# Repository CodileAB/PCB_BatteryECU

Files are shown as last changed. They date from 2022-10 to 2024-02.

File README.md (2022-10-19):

Wolley Battery ECU
==================

This is the KiCad project for the Wolley Battery ECU.

Specifications
--------------

| Name | Value |
| --- | --- |
| PCB layers | 2 |
| PCB width | 103.20 mm |
| PCB height | 117.00 mm |
| Mount hole diameter | 3.20 mm |
| Bus voltage | 5 V |
| Max current | 5 A |
| Number of cells | 10 |
| Cell type | Ni-MH (AA) |
| Integrated charging | Yes |

Key Components
--------------

| Component | Part | Details |
| --- | ---- | --- |
| MCU | Infineon XMC1404_F064X200A | ARM Cortex-M0, 32-bit, 48 MHz, 200 kB flash |
| Step-down voltage regulator | TI LM22679TJ-5.0 | 42 V to 5 V switching regulator, 5 A |
| CAN transceiver | Infineon TLE7251VSJ | |
| Current sensor | MPS MCS1803GS-05P | Hall effect current sensor, 5 A |
| Temperature sensor | TI LM35DM | Precision centigrade temperature sensor |
| Battery charger | Maxim MAX1640 | Adjustable-output, switch-mode current sources with synchronous rectifier |

Licence
-------

Licenced under the CERN Open Hardware Licence v1.2.

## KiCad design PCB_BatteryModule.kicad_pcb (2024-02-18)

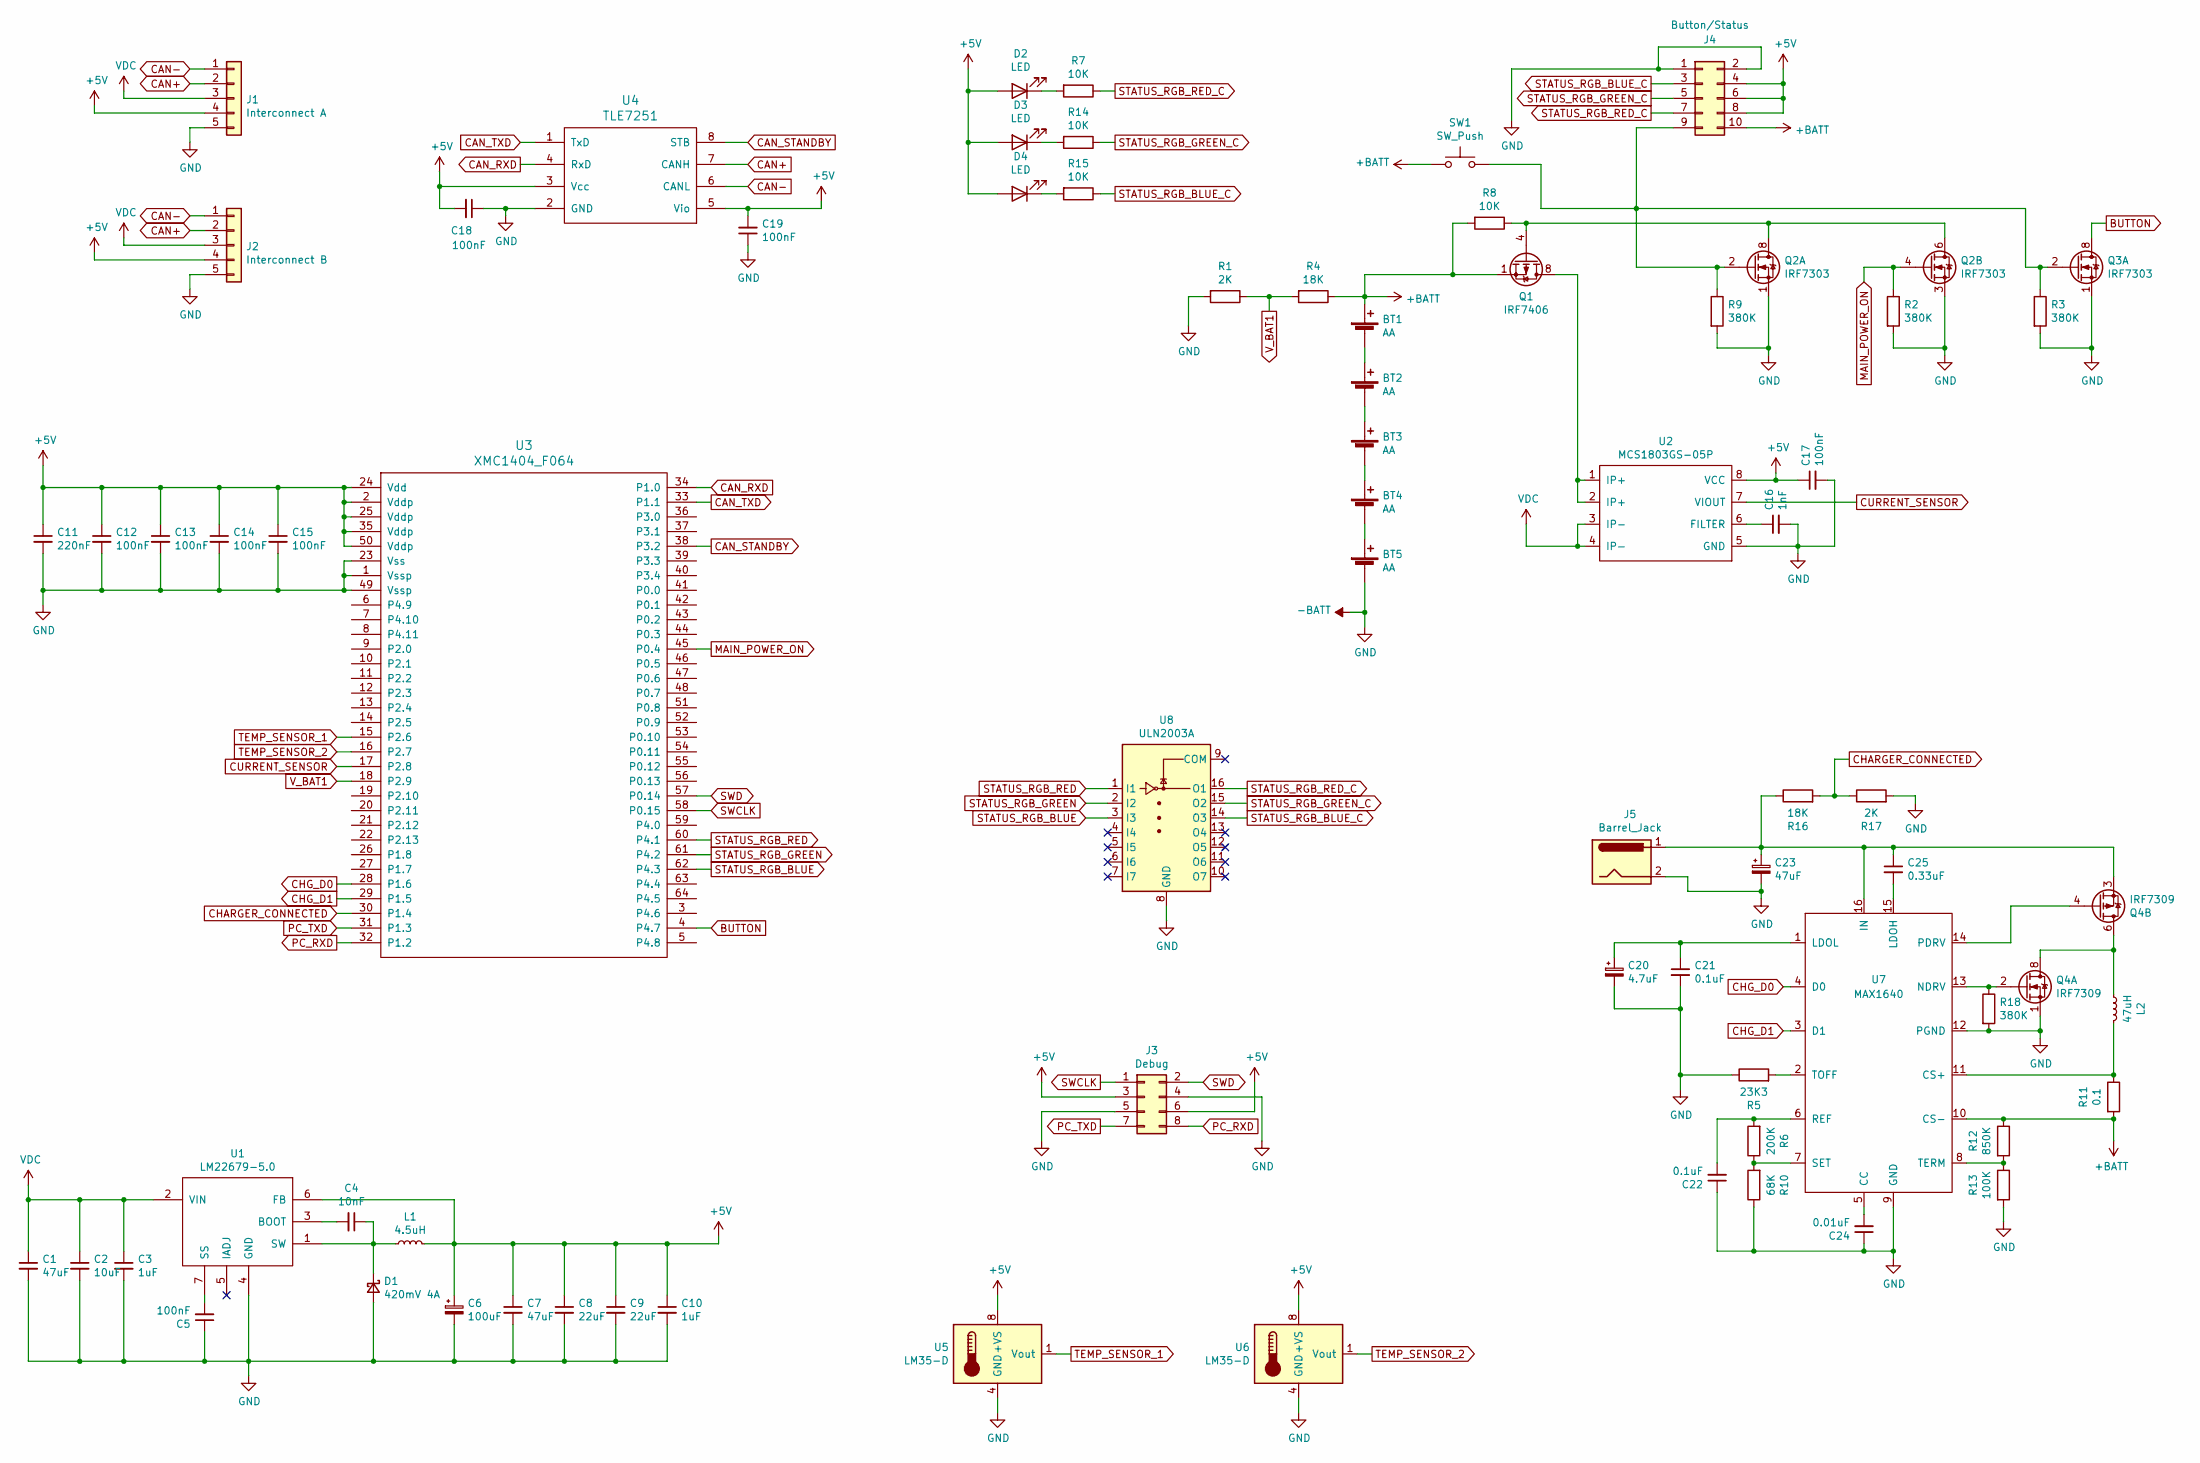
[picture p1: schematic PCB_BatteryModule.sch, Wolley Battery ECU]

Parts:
BT1, BT2, BT3, BT4, BT5: AA; Battery_AA_THT_Keystone_590
C1, C7: 47uF; C_0805_HandSoldering
C2: 10uF; C_0805_HandSoldering
C3, C10: 1uF; C_0805_HandSoldering
C4: 10nF; C_0805_HandSoldering
C5, C12, C13, C14, C15, C17, C18, C19: 100nF; C_0805_HandSoldering
C6: 100uF; CP_EIA-7343-43_Kemet-X_Pad2.25x2.55mm_HandSolder
C8, C9: 22uF; C_0805_HandSoldering
C11: 220nF; C_0805_HandSoldering
C16: 1nF; C_0805_HandSoldering
C20: 4.7uF; C_0805_HandSoldering
C21, C22: 0.1uF; C_0805_HandSoldering
C23: 47uF; CP_EIA-7343-43_Kemet-X_Pad2.25x2.55mm_HandSolder
C24: 0.01uF; C_0805_HandSoldering
C25: 0.33uF; C_0805_HandSoldering
D1: 420mV 4A; D_SMC
D2, D3, D4: LED; LED_0805_2012Metric_Pad1.15x1.40mm_HandSolder
J1: Interconnect A; WolletInterconnect_THT_Angeled
J2: Interconnect B; WolletInterconnect_THT_Angeled
J3: Debug; Pin_Header_Straight_2x04_Pitch2.54mm_SMD
J4: Button/Status; PinHeader_2x05_P2.54mm_Horizontal
J5: Barrel_Jack; BarrelJack_CUI_PJ-036AH-SMT_Horizontal
L1: 4.5uH; Inductor_SMD_Bourns_SRR1280
L2: 47uH; Inductor_SMD_Bourns_SRR1280
Q1: IRF7406; SOIC-8_3.9x4.9mm_P1.27mm
Q2, Q3: IRF7303; SOIC-8_3.9x4.9mm_P1.27mm
Q4: IRF7309; SOIC-8_3.9x4.9mm_P1.27mm
R1, R17: 2K; C_0805_HandSoldering
R2, R3, R9, R18: 380K; C_0805_HandSoldering
R4, R16: 18K; C_0805_HandSoldering
R5: 23K3; C_0805_HandSoldering
R6: 200K; C_0805_HandSoldering
R7, R8, R14, R15: 10K; C_0805_HandSoldering
R10: 68K; C_0805_HandSoldering
R11: 0.1; C_2010_5025Metric_HandSoldering
R12: 850K; C_0805_HandSoldering
R13: 100K; C_0805_HandSoldering
SW1: SW_Push; CK_Switch_KSC_Series
U1: LM22679-5.0; TO-263-7_TabPin8
U2: MCS1803GS-05P; SOIC-8_3.9x4.9mm_P1.27mm
U3: XMC1404_F064; TQFP-64_10x10mm_Pitch0.5mm_Handsoldering
U4: TLE7251; Infineon_PG-DSO-8-43
U5, U6: LM35-D; SOIC-8_3.9x4.9mm_P1.27mm
U7: MAX1640; QSOP-16_3.9x4.9mm_P0.635mm
U8: ULN2003A; SOIC-16_3.9x9.9mm_P1.27mm

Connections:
+5V: C6.1, C7.1, C8.1, C9.1, C10.1, C11.1, C12.1, C13.1, C14.1, C15.1, C17.1, C18.2, C19.2, D2.2 (A), D3.2 (A), D4.2 (A), J1.4, J2.4, J3.3, J3.6, J4.4, J4.6, J4.8, L1.2, U1.6 (FB), U2.8 (VCC), U3.2 (Vddp), U3.24 (Vdd), U3.25 (Vddp), U3.35 (Vddp), U3.50 (Vddp), U4.3 (Vcc), U4.5 (Vio), U5.8 (+VS), U6.8 (+VS)
+BATT: BT1.1 (+), J4.10, Q1.1 (S), Q1.2 (S), Q1.3 (S), R4.1, R8.2, R11.2, R12.1, SW1.1, U7.10 (CS-)
-BATT: BT5.2 (-), C1.2, C2.2, C3.2, C5.1, C6.2, C7.2, C8.2, C9.2, C10.2, C11.2, C12.2, C13.2, C14.2, C15.2, C16.2, C17.2, C18.1, C19.1, C20.2, C21.2, C22.1, C23.2, C24.1, D1.2 (A), J1.5, J2.5, J3.4, J3.5, J4.1, J4.2, J5.2, Q2.1 (S), Q2.3 (1), Q3.1 (S), Q4.1 (S), R1.2, R2.2, R3.2, R5.1, R9.2, R10.1, R13.2, R17.2, R18.2, U1.4 (GND), U2.5 (GND), U3.1 (Vssp), U3.23 (Vss), U3.49 (Vssp), U4.2 (GND), U5.4 (GND), U6.4 (GND), U7.9 (GND), U7.12 (PGND), U8.8 (GND)
BUTTON: Q3.7 (D), Q3.8 (D), U3.4 (P4.7)
CAN+: J1.2, J2.2, U4.7 (CANH)
CAN-: J1.1, J2.1, U4.6 (CANL)
CAN_RXD: U3.34 (P1.0), U4.4 (RxD)
CAN_STANDBY: U3.38 (P3.2), U4.8 (STB)
CAN_TXD: U3.33 (P1.1), U4.1 (TxD)
CHARGER_CONNECTED: R16.2, R17.1, U3.30 (P1.4)
CHG_D0: U3.28 (P1.6), U7.4 (D0)
CHG_D1: U3.29 (P1.5), U7.3 (D1)
CURRENT_SENSOR: U2.7 (VIOUT), U3.17 (P2.8)
MAIN_POWER_ON: Q2.4 (G), R2.1, U3.45 (P0.4)
unnamed: BT1.2 (-), BT2.1 (+)
unnamed: BT2.2 (-), BT3.1 (+)
unnamed: BT3.2 (-), BT4.1 (+)
unnamed: BT4.2 (-), BT5.1 (+)
unnamed: C4.1, D1.1 (K), L1.1, U1.1 (SW)
unnamed: C4.2, U1.3 (BOOT)
unnamed: C5.2, U1.7 (SS)
unnamed: C16.1, U2.6 (FILTER)
unnamed: C20.1, C21.1, U7.1 (LDOL)
unnamed: C22.2, R6.2, U7.6 (REF)
unnamed: C23.1, C25.1, J5.1, Q4.3 (1), R16.1, U7.16 (IN)
unnamed: C24.2, U7.5 (CC)
unnamed: C25.2, U7.15 (LDOH)
unnamed: D2.1 (K), R7.2
unnamed: D3.1 (K), R14.2
unnamed: D4.1 (K), R15.2
unnamed: J4.9, Q2.2 (G), Q3.2 (G), R3.1, R9.1, SW1.2
unnamed: L2.1, Q4.5 (D), Q4.6 (D), Q4.7 (D), Q4.8 (D)
unnamed: L2.2, R11.1, U7.11 (CS+)
unnamed: Q1.4 (G), Q2.5 (D), Q2.6 (D), Q2.7 (D), Q2.8 (D), R8.1
unnamed: Q1.5 (D), Q1.6 (D), Q1.7 (D), Q1.8 (D), U2.1 (IP+), U2.2 (IP+)
unnamed: Q4.2 (G), R18.1, U7.13 (NDRV)
unnamed: Q4.4 (G), U7.14 (PDRV)
unnamed: R5.2, U7.2 (TOFF)
unnamed: R6.1, R10.2, U7.7 (SET)
unnamed: R12.2, R13.1, U7.8 (TERM)
PC_RXD: J3.8, U3.32 (P1.2)
PC_TXD: J3.7, U3.31 (P1.3)
STATUS_RGB_BLUE: U3.62 (P4.3), U8.3 (I3)
STATUS_RGB_BLUE_C: J4.3, R15.1, U8.14 (O3)
STATUS_RGB_GREEN: U3.61 (P4.2), U8.2 (I2)
STATUS_RGB_GREEN_C: J4.5, R14.1, U8.15 (O2)
STATUS_RGB_RED: U3.60 (P4.1), U8.1 (I1)
STATUS_RGB_RED_C: J4.7, R7.1, U8.16 (O1)
SWCLK: J3.1, U3.58 (P0.15)
SWD: J3.2, U3.57 (P0.14)
TEMP_SENSOR_1: U3.15 (P2.6), U5.1 (Vout)
TEMP_SENSOR_2: U3.16 (P2.7), U6.1 (Vout)
VDC: C1.1, C2.1, C3.1, J1.3, J2.3, U1.2 (VIN), U2.3 (IP-), U2.4 (IP-)
V_BAT1: R1.1, R4.2, U3.18 (P2.9)

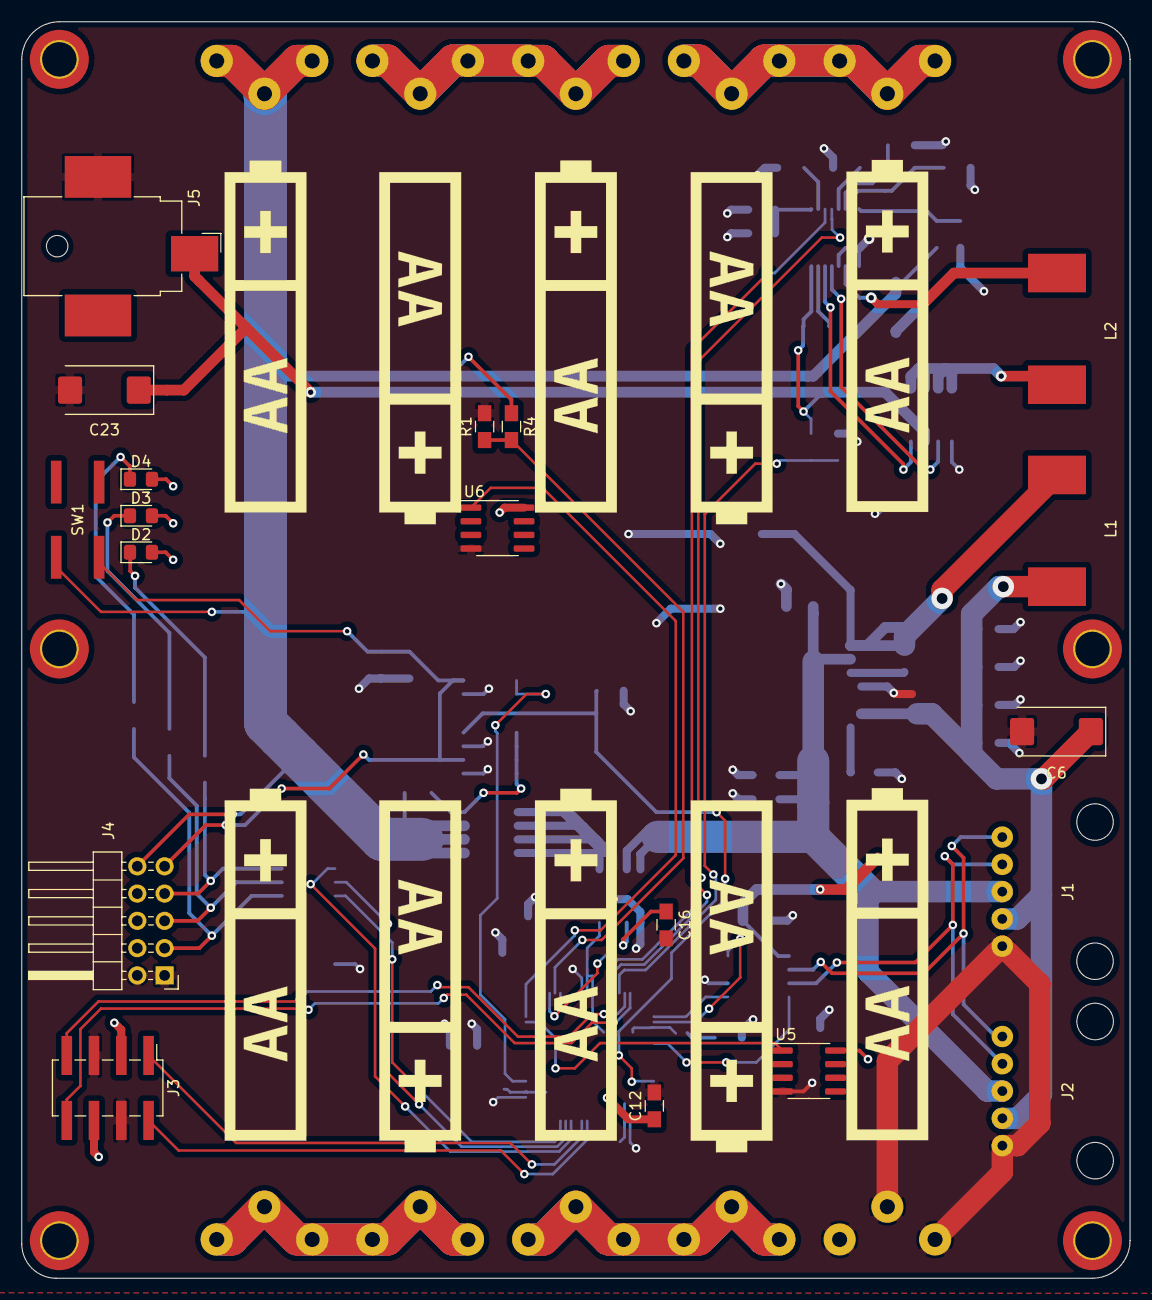
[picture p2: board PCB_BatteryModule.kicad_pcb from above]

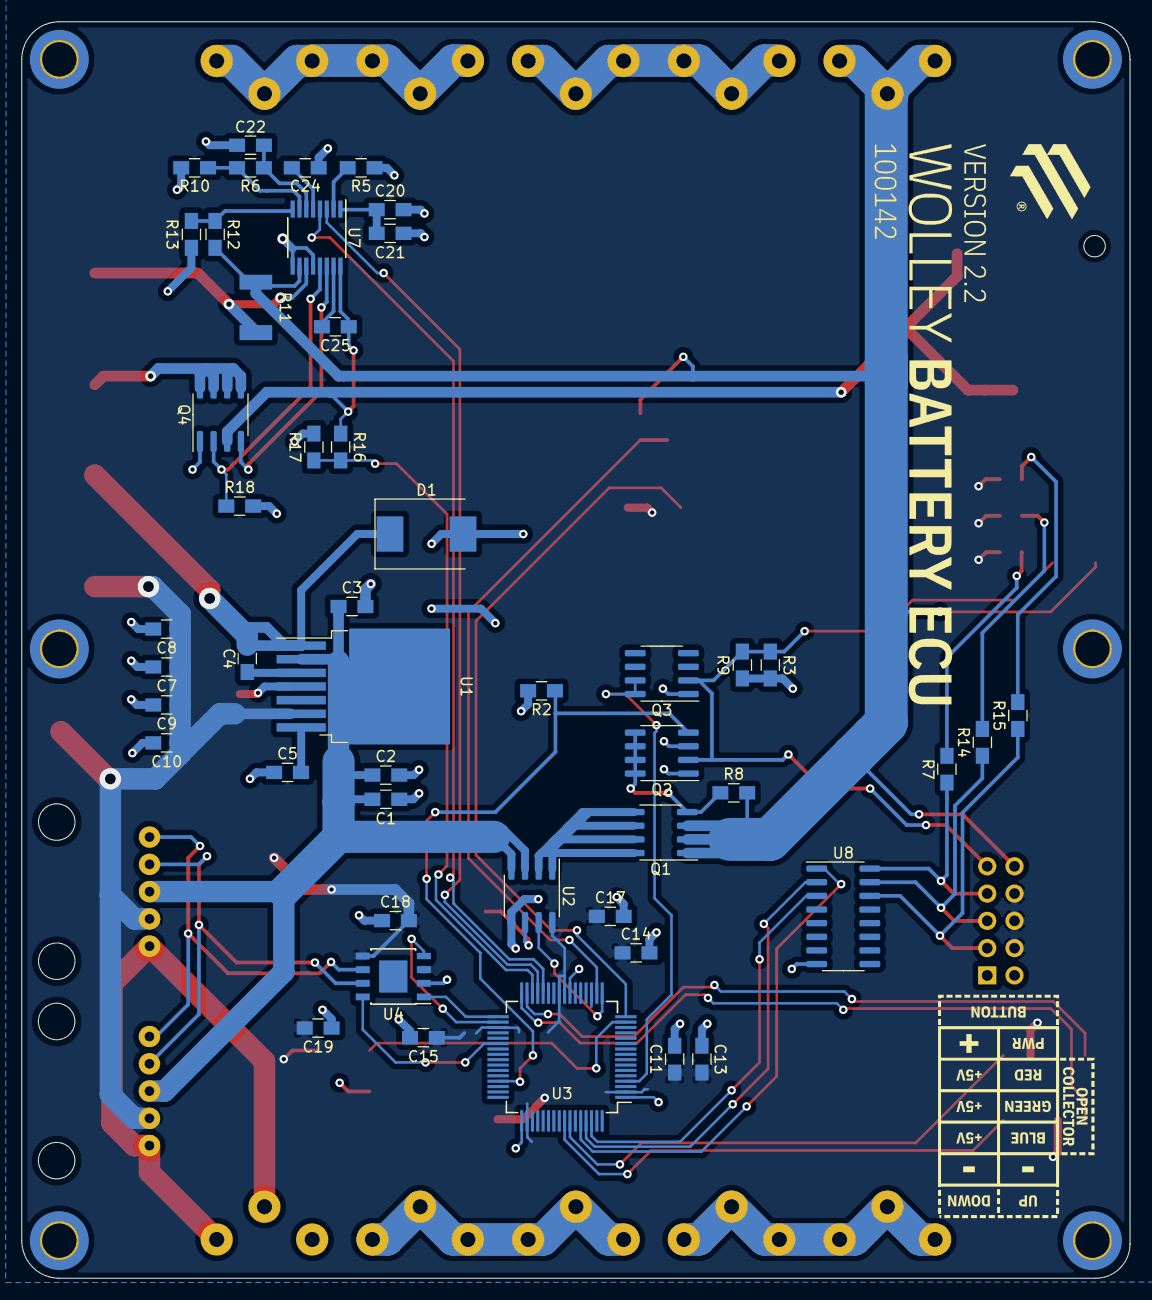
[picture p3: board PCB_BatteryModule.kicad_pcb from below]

Board: 2 copper layers, 103.2 x 117.0 mm, 72 parts (48 on the bottom side), 54 nets.

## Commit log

2021-10-28 Added files for version 1.0
    [PCB_BatteryModule.kicad_pcb, PCB_BatteryModule.sch]
2021-10-31 Add more info to the schematic and PCB
    [PCB_BatteryModule.kicad_pcb, PCB_BatteryModule.sch]
2021-11-06 Change the 0.1 uF capacitors to 100 nF which is the same
    [PCB_BatteryModule.sch]
2021-11-06 Add the 5.0 suffix to the voltage regulator to make it more specific
    [PCB_BatteryModule.sch]
2021-11-06 Bump the date
    [PCB_BatteryModule.sch]
2022-08-17 Use AA Ni-Mh cells instead of 18650 Li-ion
    [PCB_BatteryModule.kicad_pcb, PCB_BatteryModule.sch]
2022-10-13 Version 2.0 with a lot of improvements
    [PCB_BatteryModule.kicad_pcb, PCB_BatteryModule.sch]
2022-11-25 Fix bug in the charger circuit where the P-channel mosfet was connected mirrored
    [PCB_BatteryModule.kicad_pcb, PCB_BatteryModule.sch]
2023-02-25 Update the version and part number text
    [PCB_BatteryModule.kicad_pcb]
2023-02-26 Update document data
    [PCB_BatteryModule.kicad_pcb, PCB_BatteryModule.sch]
2024-01-25 Add a pull-down resistor to the charger n-channel mosfet
    Adding a pull-down resistor to the gate of the n-channel mosfet
    prevents current from flowing through it when there is no charger voltage.
    [PCB_BatteryModule.kicad_pcb, PCB_BatteryModule.sch]
2024-01-27 Use the correct footprint for the button
    [PCB_BatteryModule.kicad_pcb, PCB_BatteryModule.sch]
2024-01-28 Change the D1 footprint to be regular SMC one instead of the handsoldering version
    [PCB_BatteryModule.kicad_pcb, PCB_BatteryModule.sch]
2024-02-18 Switch out the old logo to the new one and update the partnumber
    [PCB_BatteryModule.kicad_pcb]
2024-02-18 Update document revision etc.
    [PCB_BatteryModule.kicad_pcb, PCB_BatteryModule.sch]
